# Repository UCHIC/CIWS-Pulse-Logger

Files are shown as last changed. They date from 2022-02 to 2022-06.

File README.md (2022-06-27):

# CIWS-Pulse-Datalogger

This repository contains hardware and software designs for the Pulse-Datalogger, a device that can be used to collect high resolution water use data on magnetically-driven residential water meters. The datalogger is designed to read magnetic field information from a magnetometer sensor attached to a magnetically-driven, positive-displacement water meter. 

Firmware: The Firmware folder contains code written for the datalogger.

Hardware: The Hardware folder contains hardware design information for off-the-shelf components as well as a 
manufacturable PCB.

## Operation
The device is made up of an ATMEGA328P microcontroller chip and three peripherial systems. These are an RTC(Real Time Clock), Magnetometer, and SD Card. The magnetometer reads magnetic data from the water meter and inturrupts the microcontroller when a threshold is passed. The RTC minimizes time drift by inturrupting the micronctoller at the start of every day. On this inturrupt it resets its time-keeping values to sync it with the RTC time. The SD Card stores water pulse data.

## Setup
Strap the device to the meter and connect the device to a computer via USB-Serial connector. Send a character to start communication. Answer the questions asked by the device with a `y` or `n` and fill in any requested information. Immediatly after answering those two questions the device will start to measure magnetic data to set the threshold for the magnetometer. Water must be turned on in the house to properly configure the thresholds. If you miss the calibration time restart the device and try again. After calibration the device automatically begins recording water data to the SD Card. To collect water data hit the restatrt button on the device and collect the SD Card. Water data is organised into different files for each day of data recorded. Each file contains a file header with the site ID, device ID, and date and time of data collection started. After the header each pulse is stored on a new line and is represented as an integer value. The interger value represents the milliseconds since the last pulse. 

## Cyberinfrastructure for Intelligent Water Supply (CIWS) 

CIWS is a project funded by the U.S. National Science Foundation to develop cyberinfrastructure for smart water metering and high resolution water-use data collection. We are developing systems for high resolution residential water consumption data collection, processing and analysis.

## Sponsors and Credits


This work was supported by National Science Foundation Grant [CBET 1552444](https://www.nsf.gov/awardsearch/showAward?AWD_ID=1552444). Any opinions, findings, and conclusions or recommendations expressed in this material are those of the author(s) and do not necessarily reflect the views of the National Science Foundation.

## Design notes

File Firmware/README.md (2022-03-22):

This directory contains code for a Full-Pulse resolution logger device. Compatible with the Arduino IDE.

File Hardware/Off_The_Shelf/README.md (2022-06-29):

# Off the Shelf
Instructions and parts list for a full pulse resolution device.

## Parts
See [here.](https://github.com/UCHIC/CIWS-Pulse-Logger/blob/main/Hardware/Off_The_Shelf/Full_Res_Board.csv)

## Instructions
These instructions use the reference names in the parts csv. The hole identifiers are printed on the board. Solder each part into the position specified.

1. Attach pin 1 of IC1 to E1 on the Board.
2. Attach IC2 pins GND to E30 and SQW to E26.
3. Attach IC3 pins CS to F24 and CD to F30.
4. Attach X1 to C9 and C10.
5. Attach C1 to A9 and GND.
6. Attach C2 to A10 and GND.
7. Attach two pins on B1 to A11 and A14. The other two should connect to GND. Rotate the button until its pins reach the designated holes.
8. Connect Bat to the positive and negative voltage rails respectively. A connector might additionally be used although it is not included in these instructions.
9. On the bottom of the board connect IC4 pins INT to J23 and VDD to J15.
10. Cut the header pins into a segment of 6. Arbitrarily number the pins. Pull the 5th pin out. Place the first pin into A4 with the last two pins extending off the board. They should sit flush.
11. Attach C3 to B1 and B4.
12. Place B2 into the battery holder on IC2.
13. Connect the following positions with wire.
- GND-J7
- VCC-J9
- GND-J17
- VCC-J15
- GND-J28
- VCC-J26
- J11-I29
- I10-H27
- H1-G19
- H12-G25
- H13-G24
- G2-G18
- F18-D28
- F19-C27
- F22-D6
- F23-C4
- D1-B14
- A7-VCC
- A8-GND
- A29-VCC
- A30-GND
- Connect both positive rails together.
- Connect both negative rails together.
- Connect the pin that's hanging off the board to GND.

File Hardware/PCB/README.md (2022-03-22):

# Full Resolution PCB Board
Instructions, fabrication files, and parts list for manufacturing a full resolution pcb board.

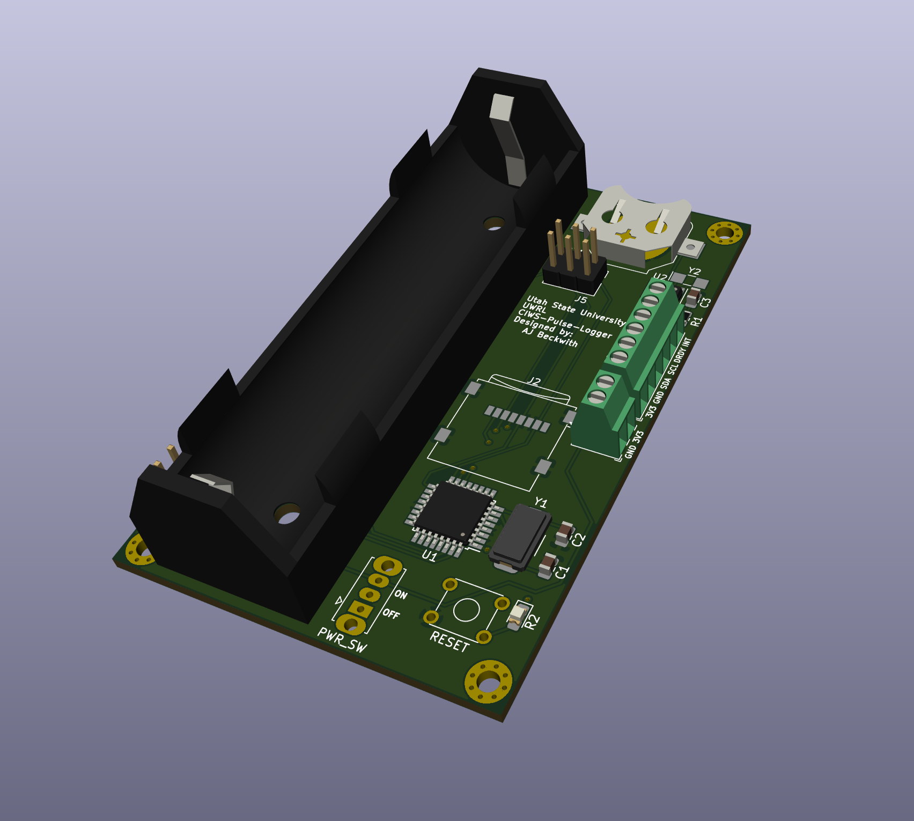
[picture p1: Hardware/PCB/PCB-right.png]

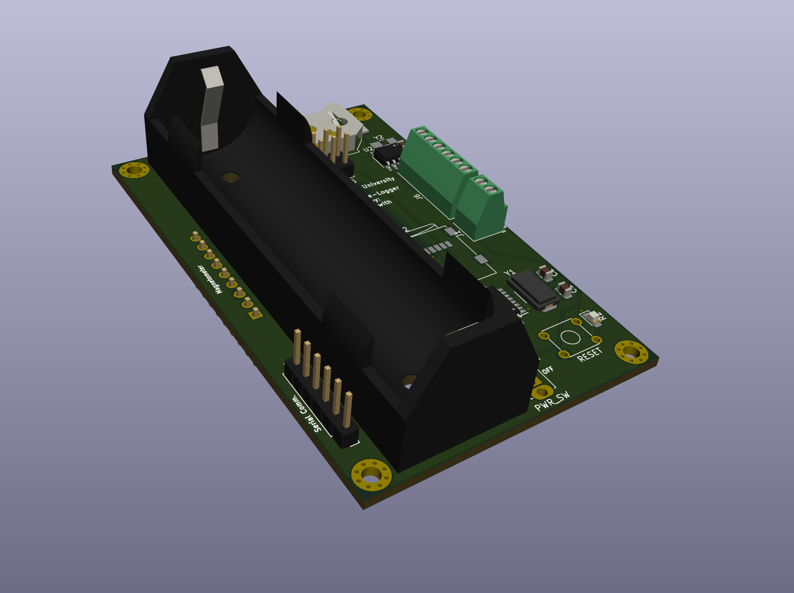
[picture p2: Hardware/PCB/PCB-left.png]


## Parts List
CSV of components available in [Hardware/PCB/KiCad/parts_list.csv](https://github.com/UCHIC/CIWS-Pulse-Logger/blob/main/Hardware/PCB/KiCad/parts_list.csv).

## Instructions
For convenience several common fabrication files have been generated and can be found in [Hardware/PCB/KiCad/FabFiles](https://github.com/UCHIC/CIWS-Pulse-Logger/tree/main/Hardware/PCB/KiCad/FabFiles).
If all the files required by your manufacturer are there, download the `.zip` file in that directory and submit it.

If your manufacturer has questions about parts direct them to the [parts csv](https://github.com/UCHIC/CIWS-Pulse-Logger/blob/main/Hardware/PCB/KiCad/parts_list.csv).

If additional fabrication files are needed download the files in [Hardware/PCB/KiCad/ProjectFiles](https://github.com/UCHIC/CIWS-Pulse-Logger/tree/main/Hardware/PCB/KiCad/ProjectFiles). In KiCad open the `.pro` file and follow your manufatures instructions for generating fabrication files.

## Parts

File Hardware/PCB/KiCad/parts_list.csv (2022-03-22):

Item | Qty | Reference(s) | Value | LibPart | Footprint | Part URL
1 | 1 | BT1 | RTC_Battery | Device:Battery_Cell | Battery:BatteryHolder_Keystone_3000_1x12mm | https://www.digikey.com/en/products/detail/keystone-electronics/3000/227440
2 | 1 | BT2 | Battery_Cell | Device:Battery_Cell | Battery:BatteryHolder_MPD_BH-18650-PC2 | https://www.digikey.com/en/products/detail/mpd-memory-protection-devices/BK-18650-PC2/2079908
3 | 2 | C1, C2 | 16pF | Device:CP1_Small | Capacitor_SMD:C_0805_2012Metric | https://www.digikey.com/en/products/detail/kyocera-avx/08051A160JAT2A/1600914
4 | 1 | C3 | 3.3uF | pspice:CAP | Capacitor_SMD:C_0805_2012Metric | https://www.digikey.com/en/products/detail/tdk-corporation/C2012JB1C335K125AC/3948680
5 | 1 | J1 | POWER_Terminal | Connector:Screw_Terminal_01x02 | TerminalBlock_Phoenix:TerminalBlock_Phoenix_MPT-0,5-2-2.54_1x02_P2.54mm_Horizontal | https://www.digikey.com/en/products/detail/phoenix-contact/1725656/267462
6 | 1 | J2 | Micro_SD_Card | Connector:Micro_SD_Card | Connector_Card:microSD_HC_Wuerth_693072010801 | https://www.digikey.com/en/products/detail/w%C3%BCrth-elektronik/693072010801/3124584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
7 | 1 | J3 | Conn_01x06_Female | Connector:Conn_01x06_Female | Connector_PinHeader_2.54mm:PinHeader_1x06_P2.54mm_Vertical | Use pins ordered with J4
8 | 1 | J4 | Conn_01x09_Female | Connector:Conn_01x09_Female | Connector_PinHeader_2.54mm:PinHeader_1x09_P2.54mm_Vertical | https://www.digikey.com/en/products/detail/w%C3%BCrth-elektronik/61301611121/4846854
9 | 1 | J5 | ISP | Connector:AVR-ISP-6 | Connector_PinHeader_2.54mm:PinHeader_2x03_P2.54mm_Vertical | https://www.digikey.com/en/products/detail/amphenol-icc-(fci)/67996-206HLF/1878485
10 | 1 | J6 | Screw_Terminal_01x06 | Connector:Screw_Terminal_01x06 | TerminalBlock_Phoenix:TerminalBlock_Phoenix_MPT-0,5-6-2.54_1x06_P2.54mm_Horizontal | https://www.digikey.com/en/products/detail/phoenix-contact/1725698/267466
11 | 1 | R1 | 1k | Device:R_US | Resistor_SMD:R_0805_2012Metric | https://www.digikey.com/en/products/detail/yageo/AC0805FR-101KL/14286726
12 | 1 | R2 | 10k | Device:R_US | LED_SMD:LED_0805_2012Metric_Castellated | https://www.digikey.com/en/products/detail/stackpole-electronics-inc/RNCP0805FTD10K0/2240262
13 | 1 | SW1 | RESET | Switch:SW_Push_Dual_x2 | Button_Switch_THT:SW_TH_Tactile_Omron_B3F-10xx | https://www.digikey.com/en/products/detail/omron-electronics-inc-emc-div/B3F-1020/44059
14 | 1 | SW2 | PWR_SW | Switch:SW_SPDT | Button_Switch_THT:SW_Slide_1P2T_CK_OS102011MS2Q | https://www.digikey.com/en/products/detail/c-k/OS102011MS2QN1/411602
15 | 1 | U1 | ATmega328P-AU | MCU_Microchip_ATmega:ATmega328P-AU | Package_QFP:TQFP-32_7x7mm_P0.8mm | https://www.digikey.com/en/products/detail/microchip-technology/ATMEGA328P-AU/1832260
16 | 1 | U2 | PCF8523T | Timer_RTC:PCF8523T | Package_SO:SOIC-8_3.9x4.9mm_P1.27mm | https://www.digikey.com/en/products/detail/nxp-usa-inc/PCF8523T-1-118/2530422
17 | 1 | Y1 | 8Mhz | Device:Crystal | Crystal:Crystal_SMD_TXC_AX_8045-2Pin_8.0x4.5mm | https://www.digikey.com/en/products/detail/ndk-america-inc/NX8045GB-8-000M-STD-CSF-4/5022982
18 | 1 | Y2 | 32.768kHz | Device:Crystal | Crystal:Crystal_SMD_EuroQuartz_EQ161-2Pin_3.2x1.5mm_HandSoldering | https://www.digikey.com/en/products/detail/micro-crystal-ag/CC7V-T1A-32-768KHZ-12-5PF-20PPM-TA-QC/10499064

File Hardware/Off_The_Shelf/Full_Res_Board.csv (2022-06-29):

Name | Qty | Reference(s) | Value | Part URL
Microcontroller | 1 | IC1 | Atmega328P | https://www.adafruit.com/product/123
RTC | 1 | IC2 | Adafruit PCF8523 | https://www.adafruit.com/product/3295
SD Slot | 1 | IC3 | BOB-00544 | https://www.digikey.com/en/products/detail/sparkfun-electronics/BOB-00544/5824094
Wire | 1 | Wire | 22 AWG Solid Core | https://www.adafruit.com/product/1311
Crystal | 1 | X1 | 8Mhz | https://www.adafruit.com/product/2213
Crystal Capacitors | 2 | C1,C2 | 20pF | Included with Crystal
Reset Button | 1 | B1 | 6mm | https://www.adafruit.com/product/367
Battery | 1 | Bat | 3.7V Li-Ion | https://www.adafruit.com/product/354
Magnetometer | 1 | IC4 | LIS3MDL | https://www.pololu.com/product/2737
Header Pins | 1 | P1 |  | https://www.adafruit.com/product/3002
Prog Capacitor | 1 | C3 | .1 uF | https://www.adafruit.com/product/753
Coin Battery | 1 | B2 | CR1220 | https://www.adafruit.com/product/380
Proto Board | 1 | Board | Perma-Proto | https://www.adafruit.com/product/1609

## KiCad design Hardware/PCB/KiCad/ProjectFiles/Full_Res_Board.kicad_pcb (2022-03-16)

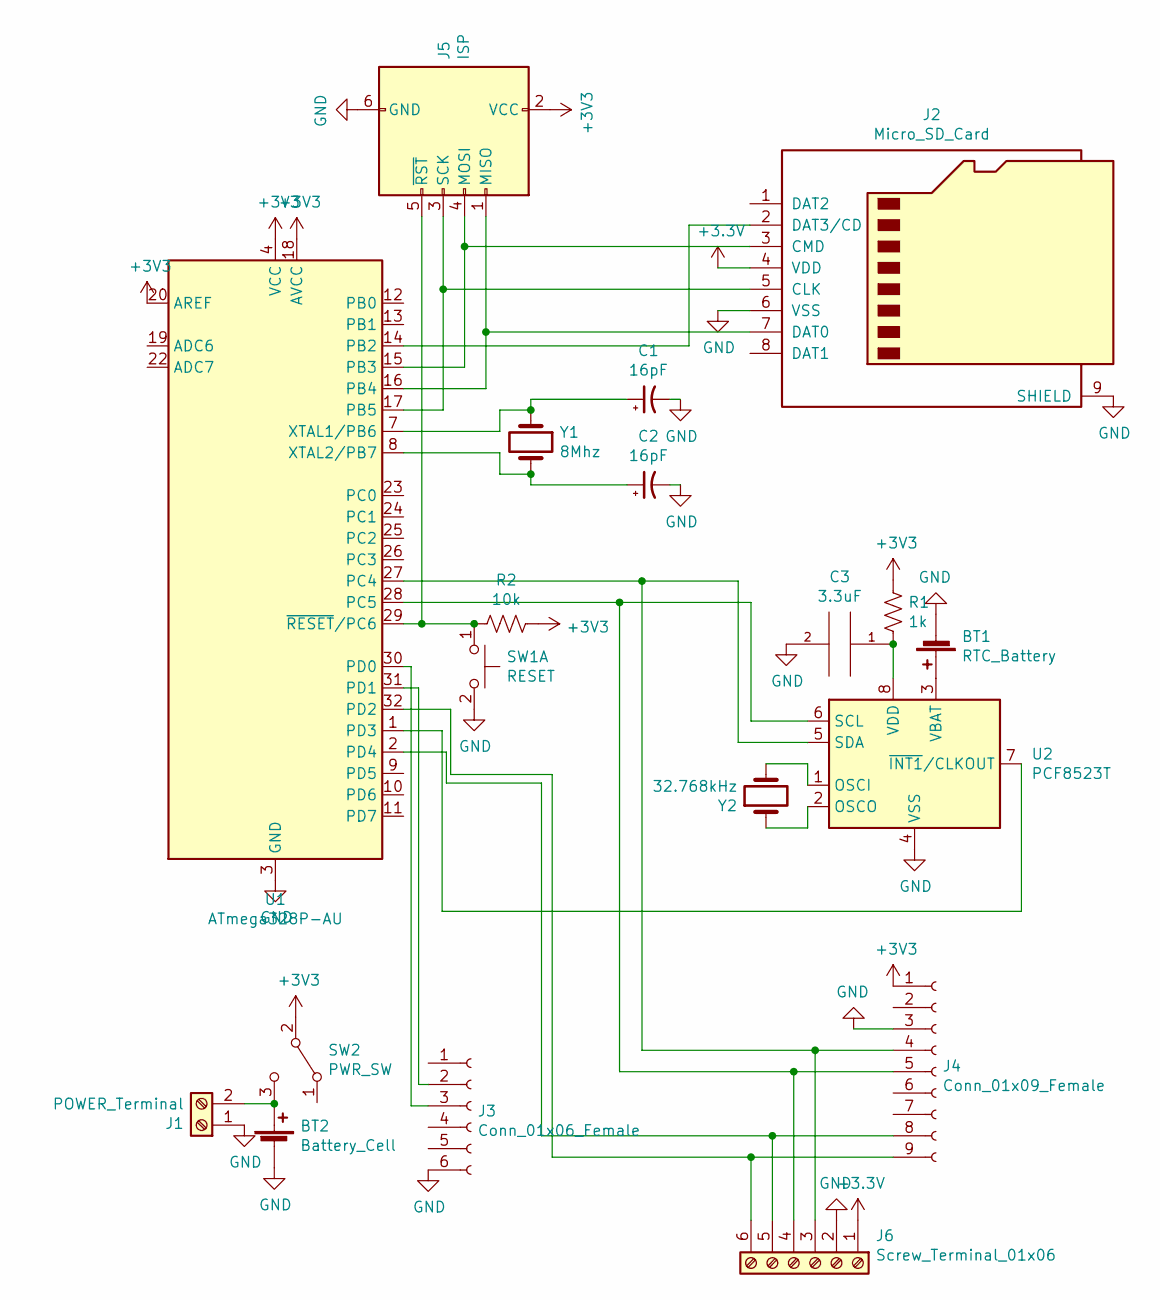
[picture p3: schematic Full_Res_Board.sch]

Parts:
BT1: RTC_Battery; BatteryHolder_Keystone_3000_1x12mm
BT2: Battery_Cell; BatteryHolder_MPD_BH-18650-PC2
C1, C2: 16pF; C_0805_2012Metric
C3: 3.3uF; C_0805_2012Metric
J1: POWER_Terminal; TerminalBlock_Phoenix_MPT-0,5-2-2.54_1x02_P2.54mm_Horizontal
J2: Micro_SD_Card; microSD_HC_Wuerth_693072010801
J3: Conn_01x06_Female; PinHeader_1x06_P2.54mm_Vertical
J4: Conn_01x09_Female; PinHeader_1x09_P2.54mm_Vertical
J5: ISP; PinHeader_2x03_P2.54mm_Vertical
J6: Screw_Terminal_01x06; TerminalBlock_Phoenix_MPT-0,5-6-2.54_1x06_P2.54mm_Horizontal
R1: 1k; R_0805_2012Metric
R2: 10k; LED_0805_2012Metric_Castellated
SW1: RESET; SW_TH_Tactile_Omron_B3F-10xx
SW2: PWR_SW; SW_Slide_1P2T_CK_OS102011MS2Q
U1: ATmega328P-AU; TQFP-32_7x7mm_P0.8mm
U2: PCF8523T; SOIC-8_3.9x4.9mm_P1.27mm
Y1: 8Mhz; Crystal_SMD_TXC_AX_8045-2Pin_8.0x4.5mm
Y2: 32.768kHz; Crystal_SMD_EuroQuartz_EQ161-2Pin_3.2x1.5mm_HandSoldering

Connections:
GND: BT1.2 (-), BT2.2 (-), C1.2, C2.2, C3.2, J1.1, J2.6 (VSS), J2.9 (SHIELD), J3.6, J4.3, J5.6 (GND), J6.2, SW1.2 (D), U1.3 (GND), U1.5 (GND), U1.21 (GND), U2.4 (VSS)
unnamed: BT1.1 (+), U2.3 (VBAT)
unnamed: BT2.1 (+), J1.2, SW2.3 (C)
unnamed: C1.1, U1.7 (XTAL1/PB6), Y1.1
unnamed: C2.1, U1.8 (XTAL2/PB7), Y1.2
unnamed: C3.1, R1.2, U2.8 (VDD)
unnamed: J2.2 (DAT3/CD), U1.14 (PB2)
unnamed: J2.3 (CMD), J5.4 (MOSI), U1.15 (PB3)
unnamed: J2.5 (CLK), J5.3 (SCK), U1.17 (PB5)
unnamed: J2.7 (DAT0), J5.1 (MISO), U1.16 (PB4)
unnamed: J3.2, U1.31 (PD1)
unnamed: J3.3, U1.30 (PD0)
unnamed: J4.4, J6.3, U1.27 (PC4), U2.5 (SDA)
unnamed: J4.5, J6.4, U1.28 (PC5), U2.6 (SCL)
unnamed: J4.8, J6.5, U1.2 (PD4)
unnamed: J4.9, J6.6, U1.32 (PD2)
unnamed: J5.5 (~RST), R2.2, SW1.1 (C), U1.29 (~RESET~/PC6)
unnamed: U1.1 (PD3), U2.7 (~INT1~/CLKOUT)
unnamed: U2.1 (OSCI), Y2.2
unnamed: U2.2 (OSCO), Y2.1

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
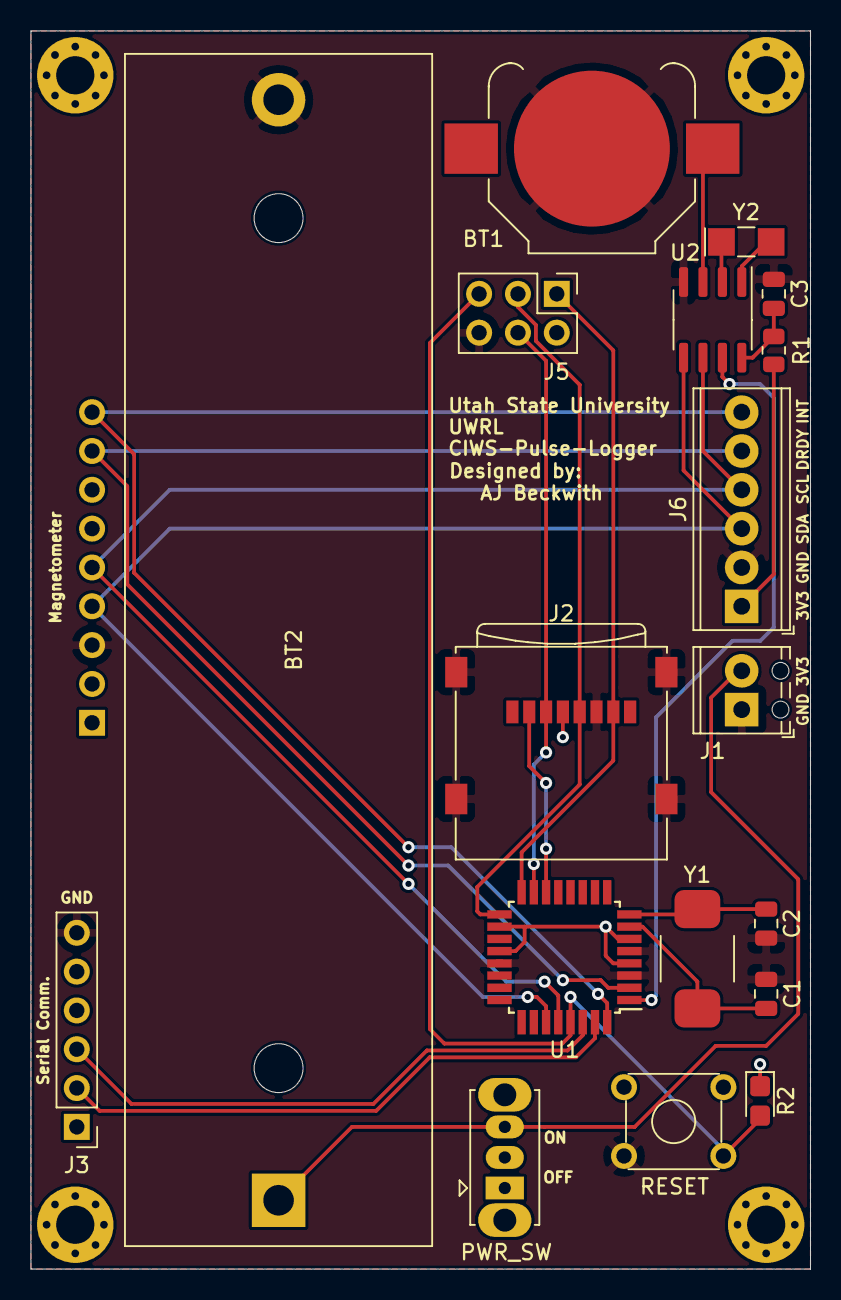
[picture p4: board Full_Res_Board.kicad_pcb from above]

Board: 2 copper layers, 51.0 x 81.0 mm, 19 parts (1 on the bottom side), 21 nets.

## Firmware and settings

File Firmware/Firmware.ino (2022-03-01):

#include <avr/sleep.h>
#include "MAG_LIS3MDL.h"
#include "RTC_PCF8523.h"
#include "timer.h"
#include "memory.h"

volatile bool newDay;                                               //declare inturrupt flag variable for RTC interrupt
volatile bool incrementTimer;                                       //declare inturrupt flag variable for timer1 interrupt
volatile uint16_t newPulse;                                         //declare inturrupt variable for MAG inturrupt

memory memory;                                                      //instantiate memory class
timer timer;                                                        //instantiate timer class
RTC RTC;                                                            //instantiate RTC class
MAG MAG;                                                            //instantiate MAG class

void setup() {
  Serial.begin(115200);                                             //start serial communication for user communication
  Serial.println("Started!");
  memory.EEPROMToMemory();                                          //read site and id from eeprom and store in class variables
  Serial.println("St");
  RTC.init();                                                       //initialize RTC
  Serial.println("ar");
  RTC.RTCToDateTime(memory.DateTime);                               //read RTC date/time and store in memory class variable
  Serial.println("te");
  timer.restartTimer();                                             //zero out timer class counter
  Serial.println("d!");
  
  ///Setup Site Number
  while (!Serial.available()){}                                     //wait until user sends data
  Serial.read();                                                    //read byte and throw away
  Serial.print(F("Is "));                                           //print first part of sentence
  Serial.print(memory.site);                                        //print site
  Serial.println(F(" the correct site? y/n"));                      //print last part of sentence
  while (!Serial.available()){}                                     //wait until user sends data
  if (Serial.read() == 'n')                                         //if data is 'n' then site is incorrect and needs to be set
  {
    Serial.println("Input three digit site number.");                 //print instructions for setting sit
    for(int a = 0; a<3; a++)                                          //for each digit in site
    {
      while (!Serial.available()){}                                     //wait until user sends data
      char temp = Serial.read();                                        //store user data in temp
      memory.site[a] = temp;                                            //store temp in site array
      Serial.println(temp);                                             //print temp
    }
  }

  ///Setup device ID
  if(memory.id[3] != 99)                                            //check if id needs to be set
  {
    Serial.println(F("What is the three digit device ID?"));          //send instructions for setting id
    for(int a = 0; a<3; a++)                                          //for each digit in site
    {
      while (!Serial.available()){}                                     //wait until user sends data
      char temp = Serial.read();                                        //store user data in temp
      memory.id[a] = temp;                                              //store temp in id array
      Serial.println(temp);                                             //print temp
    }
    memory.id[3] = 99;                                                //set so id isnt set again
  }

  ///Setup date and time
  Serial.print(F("Is "));                                           //print first part of sentence
  Serial.print(memory.DateTime);                                    //print DateTime
  Serial.println(F(" the correct date and time? y/n"));             //print last part of sentence
  while (!Serial.available()){}                                     //wait for user input
  if (Serial.read() == 'n'){                                        //if input is 'n' then date and time are incorrect and need to be set
    int pos[13]= {2, 3, 5, 6, 8, 9, 11, 12, 14, 15, 17, 18};          //declare array of import positions in DateTime array
    for(int a = 0; a<12; a++)                                         //for each position in pos
    {
      memory.DateTime[pos[a]] = '-';                                    //set each position in pos to '-'
    }
    Serial.println(F("Input date and time."));                        //send directions
    Serial.println(memory.DateTime);                                  //print DateTime
    for(int c = 0; c<12; c++)                                         //for each position in pos
    {
      while (!Serial.available()){}                                     //wait until data available                                       
      memory.DateTime[pos[c]] = Serial.read();                          //write data to DateTime
      Serial.println(memory.DateTime);                                  //print updated DateTime
    }
    RTC.DateTimeToRTC(memory.DateTime);                               //write new DateTime to RTC
    timer.restartTimer();                                             //zero out timer class counter
  }

  memory.MemoryToEEPROM();                                          //write class variables to eeprom

  ///Pin Configuration
  pinMode(2, INPUT);
  pinMode(3, INPUT_PULLUP);
  pinMode(4, INPUT);
  
  ///Class initialize
  RTC.init();                                                       //initialize RTC class
  MAG.init();                                                       //initialize MAG class
  memory.initSD();                                                  //initialize SD card

  RTC.stopAlarm();
  MAG.setThreshold();

  ///Global Variable Definitions
  newDay = false;
  incrementTimer = false;
  newPulse = 0;
  ///Inturrupt Configuration
  attachInterrupt(digitalPinToInterrupt(2), MAG_INT, CHANGE);
  attachInterrupt(digitalPinToInterrupt(3), RTC_INT, FALLING);
  ///Power use minimization
  ADCSRA = 0; //disable ADC
  power_adc_disable(); // ADC converter
  power_timer0_disable();// Timer 0
  //power_timer1_disable();// Timer 1
  power_timer2_disable();// Timer 2
  noInterrupts ();           // timed sequence follows
  // turn off brown-out enable in software
  MCUCR = bit (BODS) | bit (BODSE);  // turn on brown-out enable select
  MCUCR = bit (BODS);        // this must be done within 4 clock cycles of above
  interrupts ();
}

void loop() {
  if (newDay){
    Serial.println("newDay");
    newDay = false;
    memory.writeToSD();
    RTC.RTCToDateTime(memory.DateTime);
    RTC.stopAlarm();
    timer.restartTimer();
    memory.initSD();
  }
  
  if (newPulse){
    Serial.println("in newpulse");
    MAG.changeThreshold();
    if(digitalRead(2) && memory.addToBuffer(timer.pulseDiff(newPulse))){
      memory.writeToSD();
    }
    newPulse = 0;
  }

  if (incrementTimer){
    incrementTimer = false;
    timer.incrementKeeper();
//    digitalWrite(A3, !digitalRead(A3));
//    if(MAG.HZ != .625 && !timer.pulseInLastSecond()){ //Check MAG.HZ first to not waste time evaluating pulse in last second
//      MAG.HZto0625();
//    }
  }
  
  if (!newPulse && !newDay && !incrementTimer){
    set_sleep_mode (SLEEP_MODE_IDLE);  
    sleep_enable();
    sleep_cpu();
    noInterrupts ();           // timed sequence follows
    // turn off brown-out enable in software
    MCUCR = bit (BODS) | bit (BODSE);  // turn on brown-out enable select
    MCUCR = bit (BODS);        // this must be done within 4 clock cycles of above
    interrupts ();
  }
}

void MAG_INT(){
  newPulse = TCNT1;
}

void RTC_INT(){
  Serial.println("newday Int");
  newDay = true;
}

ISR(TIMER1_COMPA_vect){
  incrementTimer = true;
}

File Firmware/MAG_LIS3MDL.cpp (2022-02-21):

#include "MAG_LIS3MDL.h"
#include <Arduino.h>

MAG::MAG()
{
  
  
}   // End of function mag_init()

void MAG::init(){
  Wire.begin();

  // Store the configuration value for Control register 1 into buffer
  #ifdef Hz560
    MAG_WRITE(CTRL_REG1, 0x32);
    MAG_WRITE(CTRL_REG2, 0x00);
    MAG_WRITE(CTRL_REG3, 0x00);
    MAG_WRITE(CTRL_REG4, 0x04);
    MAG_WRITE(CTRL_REG5, 0x80);
    MAG_WRITE(INT_CFG, 0b00101001);
    HZ = 560;
  #endif
  #ifdef Hz300
    MAG_WRITE(CTRL_REG1, 0x52);
    MAG_WRITE(CTRL_REG2, 0x00);
    MAG_WRITE(CTRL_REG3, 0x00);
    MAG_WRITE(CTRL_REG4, 0x08);
    MAG_WRITE(CTRL_REG5, 0x80);
    MAG_WRITE(INT_CFG, 0b00101001);
    HZ = 300;
  #endif
  #ifdef Hz155
    MAG_WRITE(CTRL_REG1, 0x72);
    MAG_WRITE(CTRL_REG2, 0x00);
    MAG_WRITE(CTRL_REG3, 0x00);
    MAG_WRITE(CTRL_REG4, 0x0C);
    MAG_WRITE(CTRL_REG5, 0x80);
    MAG_WRITE(INT_CFG, 0b00101001);
    HZ = 155;
  #endif
  #ifdef Hz0.625
    MAG_WRITE(CTRL_REG1, 0b00000000);
    MAG_WRITE(CTRL_REG2, 0b00000000);
    MAG_WRITE(CTRL_REG3, 0b00000000);
    MAG_WRITE(CTRL_REG4, 0b00000000);
    MAG_WRITE(CTRL_REG5, 0b00000000);
    MAG_WRITE(INT_CFG,   0b00101001);
    HZ = .625;
  #endif
}

void MAG::HZto560(){ // need to only incude instructions that are necisary
  MAG_WRITE(CTRL_REG1, 0x32);
  MAG_WRITE(CTRL_REG2, 0x00);
  MAG_WRITE(CTRL_REG3, 0x00);
  MAG_WRITE(CTRL_REG4, 0x04);
  MAG_WRITE(CTRL_REG5, 0x80);
  MAG_WRITE(INT_CFG, 0b00101001);
  HZ = 560;
}

void MAG::HZto0625(){ // need to only incude instructions that are necisary
  Serial.println("Setting to 0.065 HZ");
  MAG_WRITE(CTRL_REG1, 0b00000000);
  MAG_WRITE(CTRL_REG2, 0b00000000);
  MAG_WRITE(CTRL_REG3, 0b00000000);
  MAG_WRITE(CTRL_REG4, 0b00000000);
  MAG_WRITE(CTRL_REG5, 0b00000000);
  MAG_WRITE(INT_CFG,   0b00101001);
  HZ = .625;
}

void MAG::setThreshold(){
  while(!digitalRead(4)){}
  int16_t temp = read_Y();
  int16_t highest = temp;
  int16_t lowest = temp;
  while(digitalRead(4)){}
  for (int a = 0; a < 1000; a++){
    while(!digitalRead(4)){}
    temp = read_Y();
    Serial.println(temp);
    if (temp > highest){
      highest = temp;
    }
    if (temp < lowest){
      lowest = temp;
    }
    while(digitalRead(4)){}
  }
  if (highest > 0){
    highthres = abs(((highest - lowest) * .7) + lowest);
    lowthres = abs(((highest - lowest) * .3) + lowest);
  }
  else{
    lowthres = abs(((highest - lowest) * .7) + lowest);
    highthres = abs(((highest - lowest) * .3) + lowest);
  }
  //highthres = ((highest + lowest)/2);
  //lowthres = ((highest + lowest)/2);
  //Serial.print("High Threshold:");
  //Serial.println(highthres);
  //Serial.print("Low Threshold:");
  //Serial.println(lowthres);
  MAG_WRITE(INT_THS_L, (highthres & 0b11111111));
  MAG_WRITE(INT_THS_H, (highthres >> 8));
  //Serial.println("Finished Threshold Set");
}

void MAG::changeThreshold(){
  if (!digitalRead(2)){
    MAG_WRITE(INT_THS_H, (lowthres >> 8) & 0b01111111);
    MAG_WRITE(INT_THS_L, (lowthres & 0b11111111));
  }
  else {
    //digitalWrite(5, HIGH);
    MAG_WRITE(INT_THS_H, (highthres >> 8) & 0b01111111);
    MAG_WRITE(INT_THS_L, (highthres & 0b11111111));
    //digitalWrite(5, LOW);
  }
}


int16_t MAG::read_Y()
{
  uint8_t high = MAG_READ(OUT_Z_H);
  uint8_t low = MAG_READ(OUT_Z_L);
  return (high << 8 | low);
}

void MAG::MAG_WRITE(uint8_t reg, uint8_t value){
  Wire.beginTransmission(MAG_ADDR);
  Wire.write(reg);
  Wire.write(value);
  Wire.endTransmission();
  return;
}

uint8_t MAG::MAG_READ(uint8_t reg){
  Wire.beginTransmission(MAG_ADDR);
  Wire.write(reg);
  Wire.endTransmission();
  Wire.requestFrom(MAG_ADDR, 1);
  return Wire.read();
}

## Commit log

2022-03-22 update hardware
    [BOM.csv]
2022-06-29 Update off the shelf
    [Full_Res_Board.csv]
